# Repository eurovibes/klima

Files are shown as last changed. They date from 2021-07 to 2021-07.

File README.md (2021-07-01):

<!-- SPDX-FileCopyrightText: 2021 Benedikt Spranger <b.spranger@linutronix.de> -->
<!-- SPDX-License-Identifier: CERN-OHL-S-2.0 -->


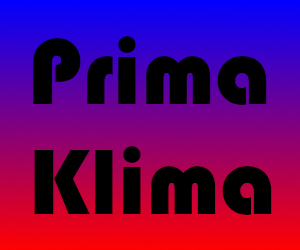
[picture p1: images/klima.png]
klima logo


# klima - A ESP8266 based humidity and temperature sensor

Klima was developed after scraping past a massive overheating of servers
caused by an unnoticed air condition failure. To be able to install the sensor
without further actions an ESP8266 wireless module was choosen.  

## License rules

klima is provided under the terms of the CERN-OHL-S license version 2 as
provided in the LICENSES/CERN-OHL-S-2.0 file.

Instead of adding license boilerplates to the individual files, klima uses
SPDX license identifiers, which are machine parseable and considered legaly
equivalent.

The SPDX license identifier in klima shall be added at the first possible
line in a file which can contain a comment. This is normally the first line
except for scripts. Scripts require the #!PATH_TO_INTERPRETER tag in the
first line; place the SPDX identifier into the second line.

The SPDX license identifier is added in form of a comment.

## Copyright and License

Copyright Benedikt Spranger 2021.
This source describes Open Hardware and is licensed under the CERNOHL-S v2.
You may redistribute and modify this source and make products using it
under the terms of the CERN-OHL-S v2
(https://ohwr.org/cern ohl s v2.txt ).
This source is distributed WITHOUT ANY EXPRESS OR IMPLIED
WARRANTY, INCLUDING OF MERCHANTABILITY, SATISFACTORY
QUALITY AND FITNESS FOR A PARTICULAR PURPOSE. Please see
the CERN-OHL-S v2 for applicable conditions.
Source location: https://github.com/eurovibes/klima
As per CERN-OHL-S v2 section 4, should You produce hardware based
on this source, You must where practicable maintain the Source Location
visible on the external case of the klima or other products you make using
this source.

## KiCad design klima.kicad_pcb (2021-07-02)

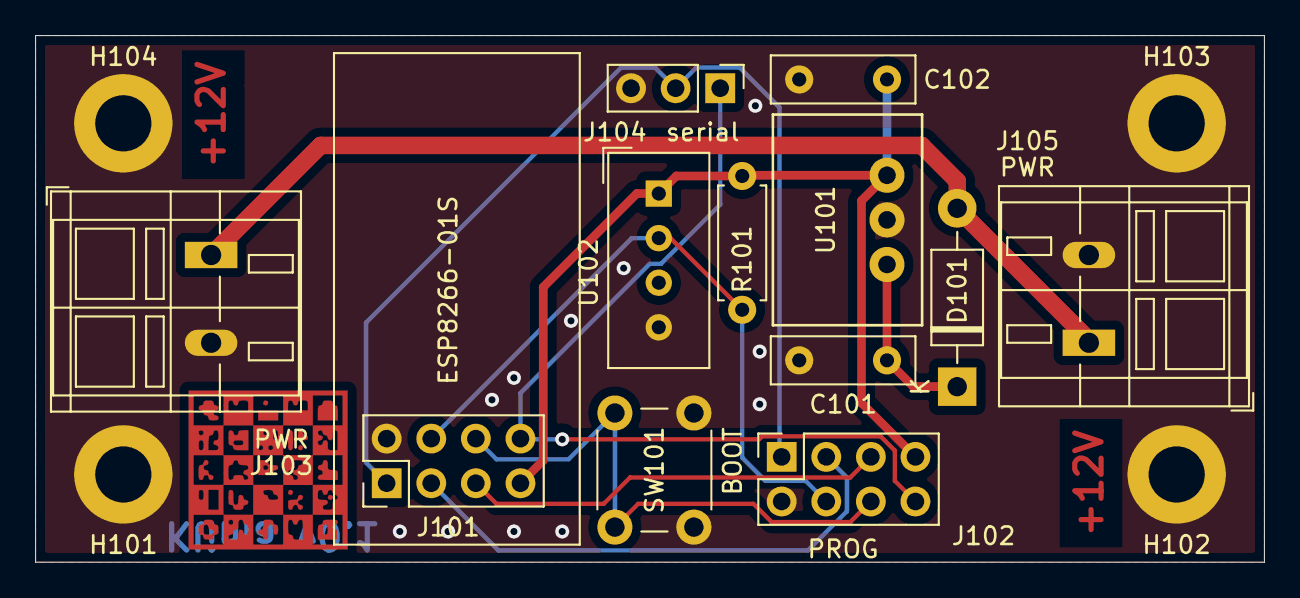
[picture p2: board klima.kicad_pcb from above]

Board: 2 copper layers, 70.0 x 30.0 mm, 16 parts (0 on the bottom side), 10 nets.

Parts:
C101, C102: C; C_Disc_D8.0mm_W2.5mm_P5.00mm
D101: 1N4004; D_DO-41_SOD81_P10.16mm_Horizontal
H101, H102, H103, H104: MountingHole_3.2mm_M3_DIN965_Pad
J101: ESP8266-01S; PinHeader_2x04_P2.54mm_Vertical
J102: PROG; PinSocket_2x04_P2.54mm_Vertical
J103, J105: PWR; TerminalBlock_WAGO_236-102_1x02_P5.00mm_45Degree
J104: serial; PinHeader_1x03_P2.54mm_Vertical
R101: 10k; R_Axial_DIN0207_L6.3mm_D2.5mm_P7.62mm_Horizontal
SW101: BOOT; SW_PUSH_6mm
U101: WPMDH1100xx1S
U102: DHT11; Aosong_DHT11_5.5x12.0_P2.54mm

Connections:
+3V3: C102.1, J101.7, J102.7, R101.1, U101.3, U102.1
+12V: D101.2, J103.1, J105.1
/EN: J101.3, J102.3
/IO0: J101.6, J102.6, SW101.1
/IO2: J101.4, J102.4, R101.2, U102.2
/RX: J101.8, J102.8, J104.1
/TX: J101.1, J102.1, J104.2
/~RST: J101.5, J102.5
GND: C101.2, C102.2, H101.1, H102.1, H103.1, H104.1, J101.2, J102.2, J103.2, J104.3, J105.2, SW101.2, U101.2, U102.4
unnamed: C101.1, D101.1, U101.1

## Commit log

2021-07-01 Initial commit
    Klima is an ESP8266 based humidity and temperature sensor.
    [klima.kicad_pcb, klima.sch]
2021-07-01 Add missing pullup
    The DHT sensor has an open collector output and need a pullup.
    Add the missing pullup.
    [klima.kicad_pcb, klima.sch]
2021-07-02 Rework ESP-01S connectors
    The ESP-01S schematic use a different numbering scheme for pinheaders.
    Revisit the schematic and consolidate schematic and footprint
    numbering scheme.
    [klima.kicad_pcb, klima.sch]

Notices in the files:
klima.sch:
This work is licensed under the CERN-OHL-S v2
